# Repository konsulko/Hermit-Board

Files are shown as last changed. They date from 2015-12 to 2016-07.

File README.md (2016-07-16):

Hermit Board
============

This is an isolator board meant for use with Atlas Scientific OEM boards.

* IMPORTANT NOTE: will unlikely work for the electroconductivity sensor due to
  the requirement the isolated ground plane to run under at least half of the
  sensor IC.

Pin mapping:

+ Pin 1 - 5V
+ Pin 2 - 5V
+ Pin 3 - VCC to buffer (NC on Rev A3)
+ Pin 4 - SDA
+ Pin 5 - INT
+ Pin 6 - SCL
+ Pin 7 - NC
+ Pin 8 - GND
+ Pin 9 - GND
+ Pin 10 - GND

Changes from v3 to v4
=====================

* Change buffer host side power supply from +5V rail to VCC
* Add VCC power plane
* Add pullup resistors to host side

Changes from v4 to v5
=====================

* Move host pullups to top side
* Add M2 screwholes
* Slightly cleanups to part placement
* Increase drill hole size for BNC connector

Changes from v5 to v6
=====================

* IMPORTANT NOTE: Do not populate the pullups R2 and R5 since INT is actually driven
* Corrected footprint for Atlas part

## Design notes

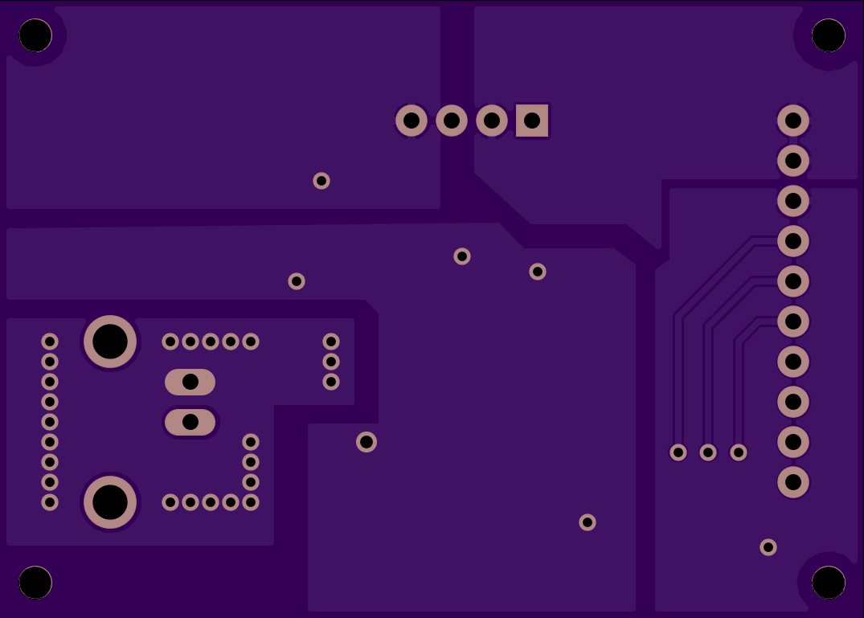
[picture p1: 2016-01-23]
bottom_A6.png

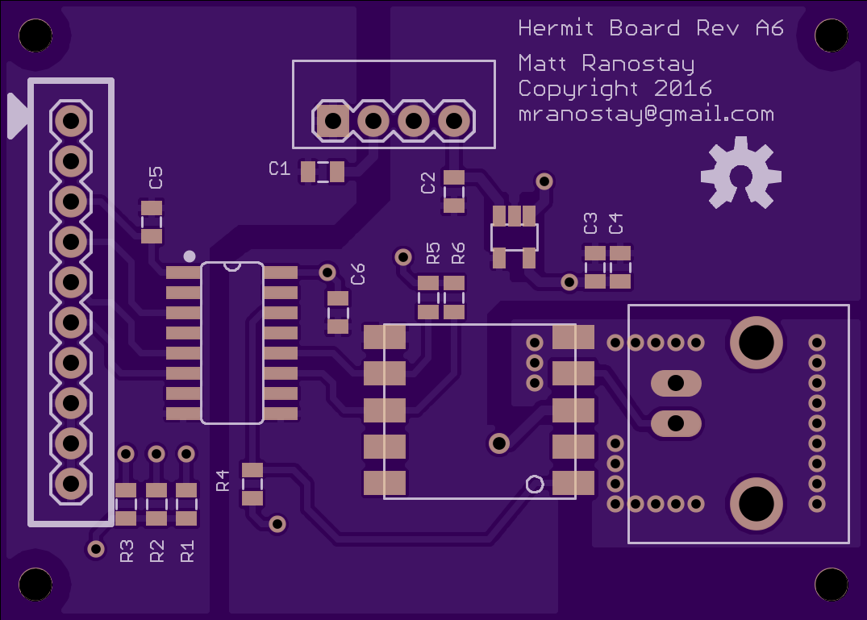
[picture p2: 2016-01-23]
top_A6.png

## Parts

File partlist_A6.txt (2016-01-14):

Partlist

Exported from Hermit Board Rev A6.brd at 1/14/16 12:34 AM

EAGLE Version 6.6.0 Copyright (c) 1988-2014 CadSoft

Assembly variant: 

Part      Value          Package              Library             Position (mm)         Orientation

ATLAS_IC  ATLAS-OEM      ATLAS-OEM            mranostay           (29.845 13.6525)      R180
C1        100nF          0805                 SparkFun-Capacitors (20.32 28.2575)       R180
C2        100nF          0805                 SparkFun-Capacitors (28.575 26.9875)      R270
C3        10uF           0805                 SparkFun-Capacitors (37.465 22.225)       R90
C4        10uF           0805                 SparkFun-Capacitors (39.0525 22.225)      R90
C5        100nF          0805                 SparkFun-Capacitors (9.525 25.0825)       R270
C6        100nF          0805                 SparkFun-Capacitors (21.2725 19.3675)     R90
MCP1755T  MCP1755T       SOT-23-5             mranostay           (32.385 24.13)        R180
R1        4.7k           0805                 SparkFun-Passives   (11.7475 7.3025)      R90
R2        4.7k           0805                 SparkFun-Passives   (9.8425 7.3025)       R90
R3        4.7k           0805                 SparkFun-Passives   (7.9375 7.3025)       R90
R4        4.7k           0805                 SparkFun-Passives   (15.875 8.5725)       R90
R5        4.7k           0805                 SparkFun-Passives   (26.9875 20.32)       R270
R6        4.7k           0805                 SparkFun-Passives   (28.575 20.32)        R270
ROE-0505S ROE-0505S      SIP4                 mranostay           (20.955 31.4325)      R0
SI8605    SI8605         SOIC16-1.27-10X3.9MM mranostay           (14.605 17.4625)      R270
U$1                      1X10                 SparkFun-Connectors (4.445 31.4325)       R270
U$2       BNCPTH         BNC                  mranostay           (42.545 12.3825)      R270

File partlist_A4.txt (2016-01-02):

Partlist

Exported from Hermit Board Rev A4.brd at 1/1/16 10:19 PM

EAGLE Version 6.6.0 Copyright (c) 1988-2014 CadSoft

Assembly variant: 

Part      Value          Package              Library             Position (mm)         Orientation

ATLAS_IC  ATLAS-OEM      ATLAS-OEM            mranostay           (44.45 52.07)         R180
C1        100nF          0805                 SparkFun-Capacitors (34.925 66.675)       R180
C2        100nF          0805                 SparkFun-Capacitors (43.18 65.405)        R270
C3        10uF           0805                 SparkFun-Capacitors (50.8 61.9125)        R90
C4        10uF           0805                 SparkFun-Capacitors (53.0225 61.9125)     R90
C5        100nF          0805                 SparkFun-Capacitors (24.13 63.5)          R270
C6        100nF          0805                 SparkFun-Capacitors (34.925 57.4675)      R90
MCP1755T  MCP1755T       SOT-23-5             mranostay           (46.99 62.5475)       R180
R1        4.7k           0805                 SparkFun-Passives   (22.86 49.53)         MR90
R2        4.7k           0805                 SparkFun-Passives   (24.4475 49.53)       MR90
R3        4.7k           0805                 SparkFun-Passives   (26.035 49.53)        MR90
R4        4.7k           0805                 SparkFun-Passives   (30.48 46.99)         R90
R5        4.7k           0805                 SparkFun-Passives   (41.5925 58.7375)     R270
R6        4.7k           0805                 SparkFun-Passives   (43.4975 58.7375)     R270
ROE-0505S ROE-0505S      SIP4                 mranostay           (35.56 69.85)         R0
SI8605    SI8605         SOIC16-1.27-10X3.9MM mranostay           (29.21 55.88)         R270
U$1                      1X10                 SparkFun-Connectors (19.05 69.85)         R270
U$2       BNCPTH         BNC                  SparkFun-Connectors (57.15 50.8)          R270

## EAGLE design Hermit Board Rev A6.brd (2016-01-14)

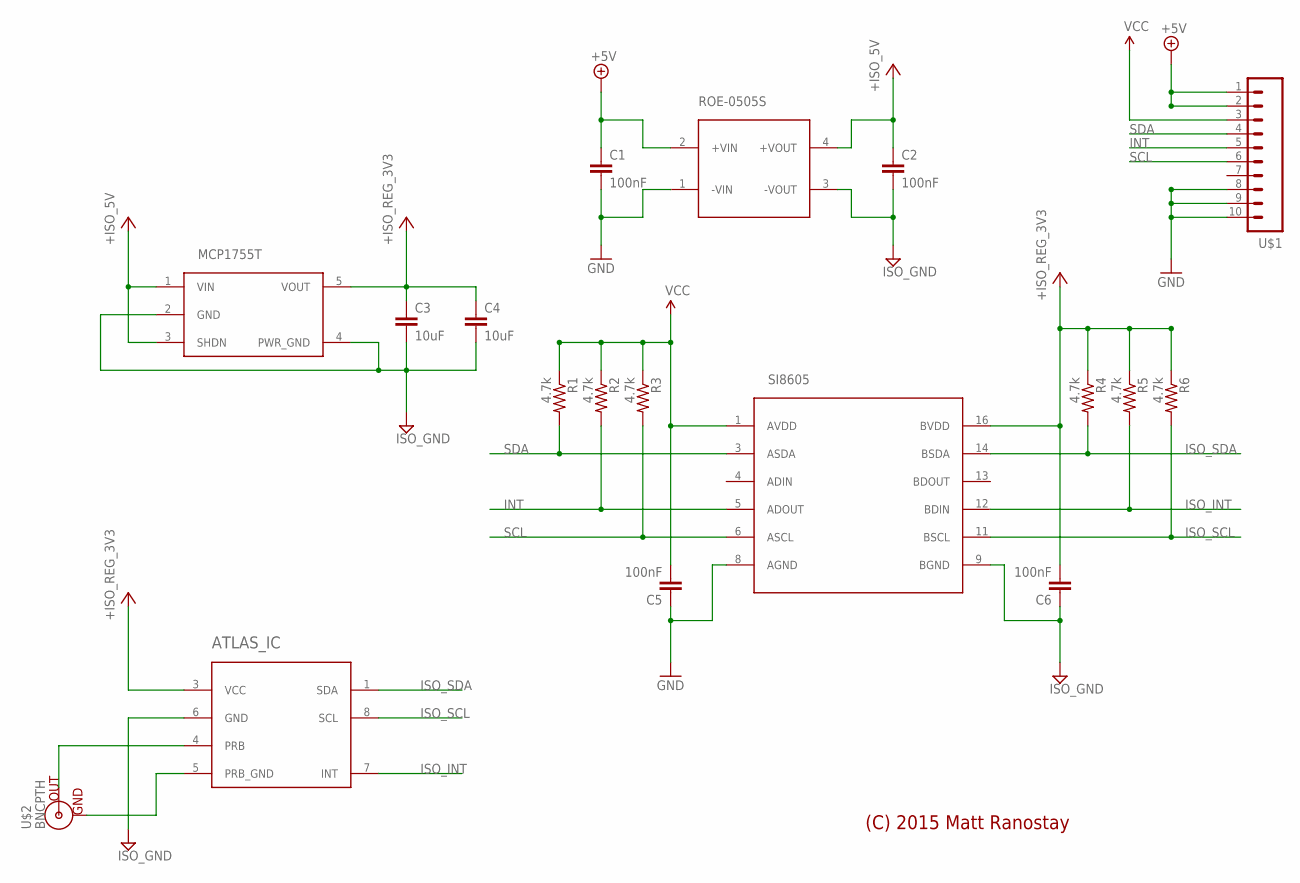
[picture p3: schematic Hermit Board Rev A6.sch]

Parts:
ATLAS_IC: ATLAS-OEM
C1, C2, C5, C6: 100nF; 0805
C3, C4: 10uF; 0805
MCP1755T: MCP1755T; SOT-23-5
R1, R2, R3, R4, R5, R6: 4.7k; 0805
ROE-0505S: ROE-0505S; SIP4
SI8605: SI8605; SOIC16-1.27-10X3.9MM
U$1: M10SILK_FEMALE_PTH; 1X10
U$2: BNCPTH; BNC

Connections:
+3V3: ATLAS_IC.3 (VCC), C3.1, C4.1, C6.2, MCP1755T.5 (VOUT), R4.1, R5.1, R6.1, SI8605.16 (BVDD)
+5V: C1.1, ROE-0505S.2 (+VIN), U$1.1, U$1.2
+ISO_5V: C2.1, MCP1755T.1 (VIN), MCP1755T.3 (SHDN), ROE-0505S.4 (+VOUT)
GND: C1.2, C5.1, ROE-0505S.1 (-VIN), SI8605.8 (AGND), U$1.8, U$1.9, U$1.10
INT: R2.2, SI8605.5 (ADOUT), U$1.5
ISO_GND: ATLAS_IC.6 (GND), C2.2, C3.2, C4.2, C6.1, MCP1755T.2 (GND), MCP1755T.4 (PWR_GND), ROE-0505S.3 (-VOUT), SI8605.9 (BGND)
ISO_INT: ATLAS_IC.7 (INT), R5.2, SI8605.12 (BDIN)
ISO_SCL: ATLAS_IC.8 (SCL), R6.2, SI8605.11 (BSCL)
ISO_SDA: ATLAS_IC.1 (SDA), R4.2, SI8605.14 (BSDA)
unnamed: ATLAS_IC.4 (PRB), U$2.S (OUT)
PRB_GND: ATLAS_IC.5 (PRB_GND), U$2.GND
SCL: R3.2, SI8605.6 (ASCL), U$1.6
SDA: R1.2, SI8605.3 (ASDA), U$1.4
VCC: C5.2, R1.1, R2.1, R3.1, SI8605.1 (AVDD), U$1.3

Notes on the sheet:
(C) 2015 Matt Ranostay

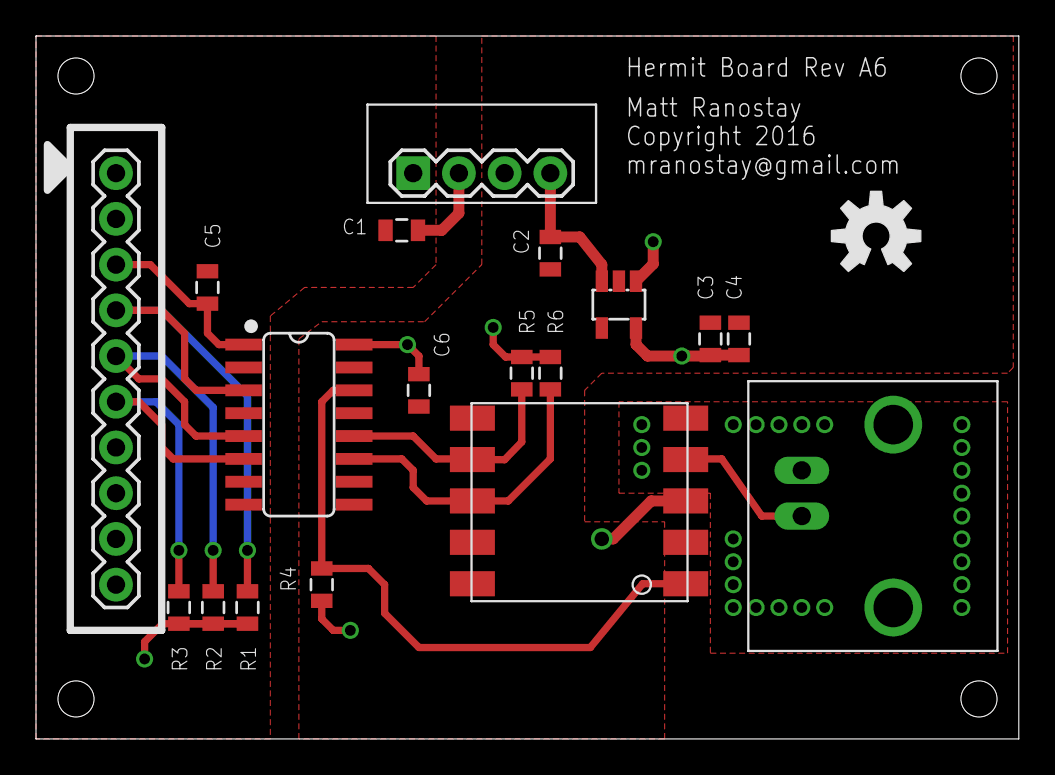
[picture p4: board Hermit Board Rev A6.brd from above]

Board: 2 copper layers, 54.6 x 39.1 mm, 19 parts (0 on the bottom side), 14 nets.

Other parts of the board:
U$3: OSHW-LOGO-M

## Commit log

2015-12-25 Add BOM partlist
2016-01-02 Renamed A to A3
    [Hermit Board Rev A3.brd, Hermit Board Rev A3.sch]
2016-01-02 Add Rev A4 schematic and board
    [Hermit Board Rev A4.brd, Hermit Board Rev A4.sch]
2016-01-02 Add pin mapping
2016-01-04 Add Rev 5
    [Hermit Board Rev A5.brd, Hermit Board Rev A5.sch]
2016-01-14 Added Hermit Board Rev A6
    [Hermit Board Rev A6.brd, Hermit Board Rev A6.sch]
2016-01-23 Add pngs of board layout
2016-07-16 Note that EC sensor will unlikely work with this isolator board.

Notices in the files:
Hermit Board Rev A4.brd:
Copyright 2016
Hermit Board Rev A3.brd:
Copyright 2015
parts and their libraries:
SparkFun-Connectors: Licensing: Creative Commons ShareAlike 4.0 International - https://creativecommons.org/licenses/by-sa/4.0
